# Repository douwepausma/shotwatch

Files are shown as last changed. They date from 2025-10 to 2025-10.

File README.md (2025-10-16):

# Shotwatch
Display the brewing time of your GAGGIA Classic Pro with Shotwatch ☕️⏱️. This handy DIY gadget allows to display the amount of seconds your GAGGIA has been running on display.
>'Shotwatch' is a combination of the words 'Espresso <ins>**Shot**</ins>' and 'Stop<ins>**watch**</ins>'

## Why?
Many times I've either forgot to start counting our lost count (counting till 20 is hard okay) for how long my shot was running for. So I thought 'why not make something that does this for me?' After some Googling I quickly found solutions to this problem online, ones that I could purchase and install myself. They were however quite expensive, and this project sounded like something I could handle myself and learn a thing or two. So I opted to do it myself. In the end I probably spend more time and money prototyping then when I would've bought a solution, but what's the fun in that?! And (spoiler alert) I even learned how to make my own pcb in this project!

## How does it work?
The Shotwatch is quite simple and consists out of only 2 components, the screen and the logic board. The logic board is hooked up in series with two wires behind the brewing switch, this turns the Shotwatch on and automatically starts counting. The number is displayed on a small OLED screen connected to the logic board. Logic board is an Arduino Pro Micro, and powered with current directly coming via the brewing switch itself. GAGGIA Classic Pro's internals are all 230 AC current, so the I created a pcb where the logic board is mounted onto that houses a transformer to get the appropriate volts and wattage.

## Bill of materials
In addition to the 3 printed parts and the Shotwatch PCB, the following parts are required. You can find all the parts below on AliExpress. Concerning the Shotwatch PCB, you can get this manufactured at PCBWay with the gerber files. And you can print the STL files for the case yourself, or find a place where you can get them printed.

|Part|Amount|
|----|---|
|HLK-10M05(10W 5V)|1x|
|Arduino Pro Micro|1x|
|Header pins 2x12|2x|
|SSD1315 Oled screen|1x|
|4pin JST female connector|1x|
|4pin JST male connector|2x|
|KF128 5.08MM pitch, 2 port screw terminal|1x|
|30cm 4 wire ribbon cable|1x|
|30cm 18 AWG cable|2x|
|Piggyback connecter (with insulation)|2x|

## Assembly
https://github.com/user-attachments/assets/8fb99642-29bd-4e3d-afc3-6cd245b8583b

## Shotwatch in action
https://github.com/user-attachments/assets/95962a83-e972-49d3-940f-4a79777042f4

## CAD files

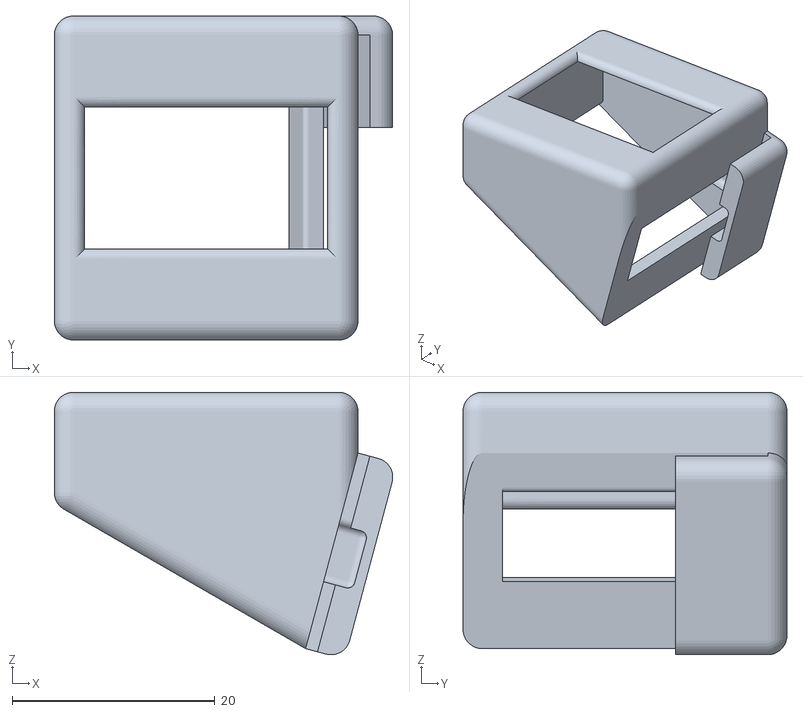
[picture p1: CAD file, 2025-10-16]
stl/GAGGIA Shotwatch Screen Case.stl
33.4 x 32.0 x 25.9

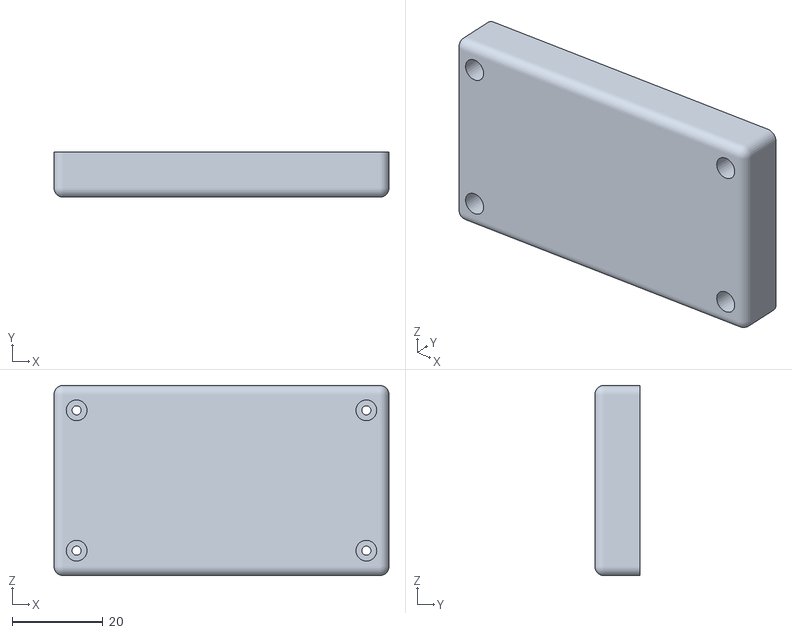
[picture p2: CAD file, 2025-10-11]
stl/GAGGIA Shotwatch Case 2-2.stl
74.0 x 10.0 x 42.0

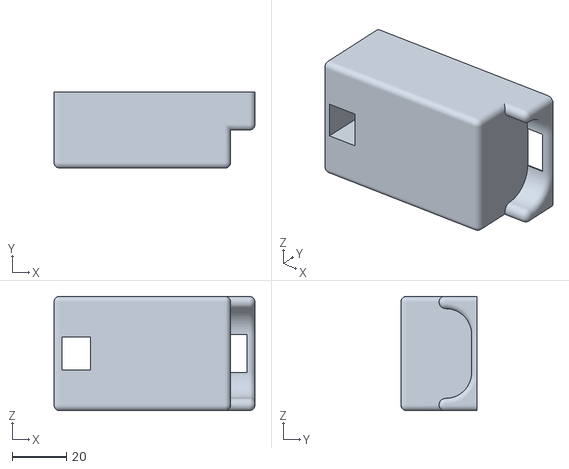
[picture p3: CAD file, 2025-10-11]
stl/GAGGIA Shotwatch Case 1-2.stl
74.0 x 28.0 x 42.0

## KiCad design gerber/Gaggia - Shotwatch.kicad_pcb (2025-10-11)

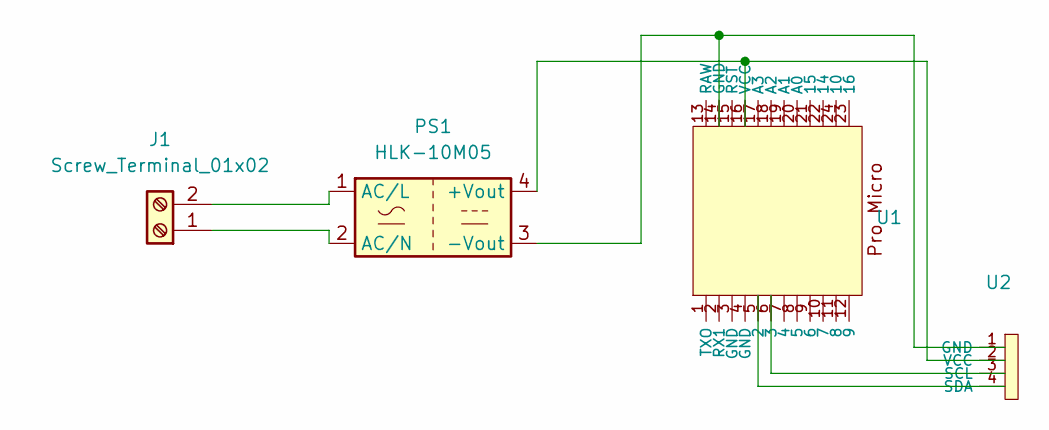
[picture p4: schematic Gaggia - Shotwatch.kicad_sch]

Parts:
J1: Screw_Terminal_01x02; TerminalBlock_MaiXu_MX126-5.0-02P_1x02_P5.00mm
PS1: HLK-10M05; Converter_ACDC_Hi-Link_HLK-10Mxx
U1: Pro Micro
U2: 4_Through_Hole_Pads

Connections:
unnamed: J1.1, PS1.2 (AC/N)
unnamed: J1.2, PS1.1 (AC/L)
unnamed: PS1.4 (+Vout), U1.16 (VCC), U2.2 (VCC)
unnamed: PS1.3 (-Vout), U1.14 (GND), U2.1 (GND)
unnamed: U1.5 (2), U2.4 (SDA)
unnamed: U1.6 (3), U2.3 (SCL)

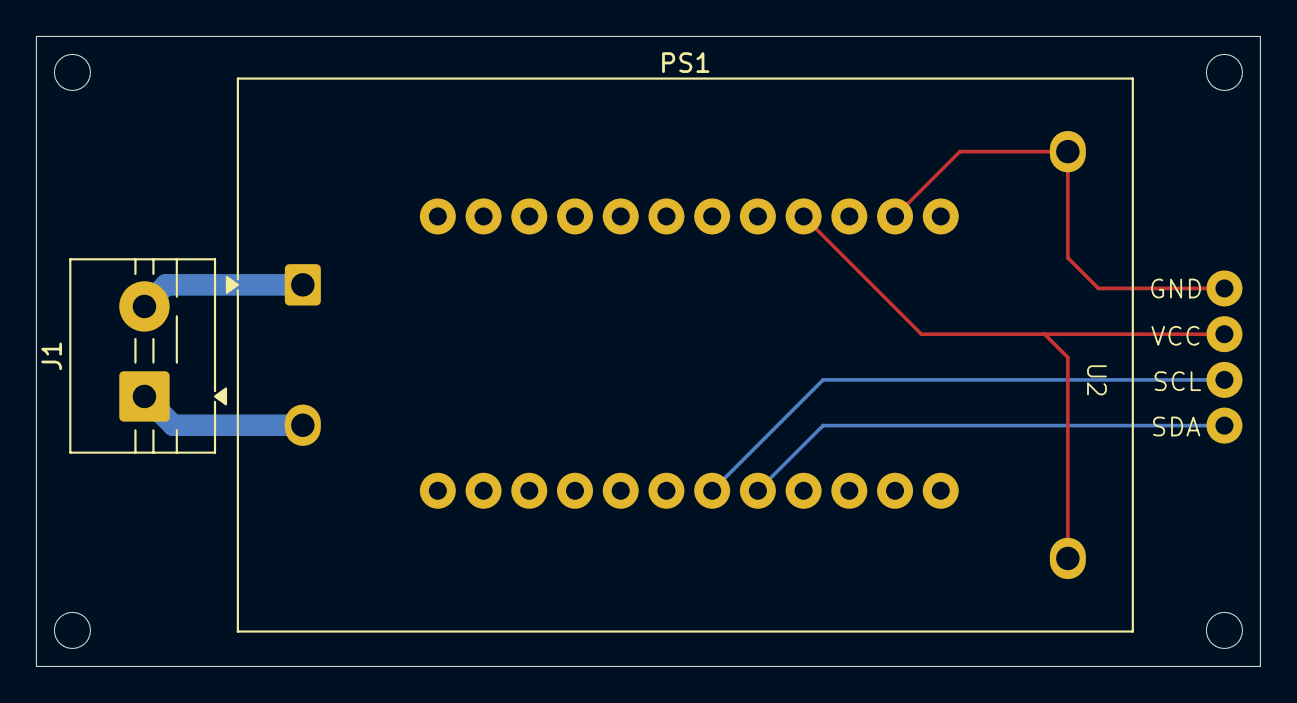
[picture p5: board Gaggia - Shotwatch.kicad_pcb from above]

Board: 2 copper layers, 68.0 x 35.0 mm, 4 parts (1 on the bottom side), 6 nets.

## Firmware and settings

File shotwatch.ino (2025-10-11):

#include <Wire.h>
#include <Adafruit_GFX.h>
#include <Adafruit_SSD1306.h>

#define SCREEN_WIDTH 128 // OLED display width, in pixels
#define SCREEN_HEIGHT 64 // OLED display height, in pixels

// Declaration for SSD1306 display connected via I2C (default address 0x3C)
#define OLED_RESET -1
Adafruit_SSD1306 display(SCREEN_WIDTH, SCREEN_HEIGHT, &Wire, OLED_RESET);

int counter = 1;

void setup() {
  // Initialize serial (optional for debugging)
  Serial.begin(9600);

  // Initialize OLED
  if (!display.begin(SSD1306_SWITCHCAPVCC, 0x3C)) {
    Serial.println(F("SSD1306 allocation failed"));
    for (;;); // Don't proceed, loop forever
  }

  // Clear display buffer
  display.clearDisplay();
  display.setRotation(2); 		// Rotate the display (it's mounted upside down)
  display.setTextSize(9); 		// Text size
  display.setTextColor(SSD1306_WHITE); 	// Text color
  display.setCursor(16, 0); 		// Position
  display.display();
  delay(1000); 				// Brief message
}

void loop() {
  display.clearDisplay();              // Clear the display
  display.setTextSize(9);              // Text size
  display.setTextColor(SSD1306_WHITE);
  display.setCursor(16, 0);        
  if(counter < 10) display.print(0);   // Add Leading zero below 10
  display.print(counter);              // Print counter
  display.display();                   // Show on screen

  counter++;                           // Increment
  delay(1000);                         // Wait 1 second
}

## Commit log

2025-10-11 add: project files
    [GAGGIA Shotwatch Case 1-2.stl, GAGGIA Shotwatch Case 2-2.stl, Gaggia - Shotwatch.kicad_pcb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]
2025-10-11 Add bill of materials to README
    Updated the README to include a bill of materials section with required parts for the Shotwatch project.
2025-10-11 Add assembly section with link to resources
    Added assembly link to the README.
2025-10-16 improve screen case
    [GAGGIA Shotwatch Screen Case.stl, screen_case_lid.stl]
